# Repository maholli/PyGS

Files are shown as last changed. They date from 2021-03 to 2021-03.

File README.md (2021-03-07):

# PyGS
Simple wifi ground station running circuitpython 



## Example Hardware Setup
As opposed to using an antenna+rotator for receiving satellites moving across the sky, another option is to use multiple antennas like this:


attached to multiple low-cost radios.

# Detailed Instructions
To replicate the above example, you'll need the following:

## Items Required
- [ ] 1ea [FeatherS2](https://www.adafruit.com/product/4769)
- [ ] 3ea RFM9x Featherwing [900 MHz](https://www.adafruit.com/product/3231) or [433MHz](https://www.adafruit.com/product/3232)
- [ ] 3ea edge-mount [SMA connectors ](https://www.adafruit.com/product/1865)
- [ ] 4ea [Stacking headers](https://www.adafruit.com/product/2830)
- [ ] Directional antennas for each of your radios. [Log Periodic](https://www.wa5vjb.com/products1.html) antennas work well. The LP400 covers 433MHz and 915MHz.
- [ ] Coax cables for each radio+antenna. Each cable should be about 450mm.
- [ ] Battery for the FeatherS2. [This would work well ](https://www.adafruit.com/product/353)
- [ ] Husky storage bin (overkill but convenient) [from Home Depot](https://www.homedepot.com/p/Husky-20-Gal-Professional-Duty-Waterproof-Storage-Container-with-Hinged-Lid-in-Black-246841/312898941)
- [ ] OPTIONAL: 2ea 100kΩ resistors (0603 work well) for battery voltage monitor

## Hardware Setup
### Antennas
1. 3D print the antenna spacer: 
2. Connect your coax and tape at the base. Ensure the coax runs on top of the center trace of the LP antenna.

### Radios & MCU
The hardware from Adafruit needs to be assembled as described below. Keep in mind you can always adapt the pin definitions in `radio_helpers.py` to meet a different hardware configuration. 
1. Assemble the radio boards with stacking headers and your edge-mount SMA connectors. Use [Adafruit's guide](https://learn.adafruit.com/radio-featherwing/assembly) as a reference.
2. Solder wires for the radio CS, RST, and IRQ signals as described below:


| Radio | CS | RST | IRQ |
|:-----: |:---:  |:---:  |:---:  |
| 1 | "C" | "B" | See pic |
| 2 | "E" | "D" | See pic |
| 3 | See pic | See pic | See pic | 

3. Now assemble the FeatherS2 with stacking headers
4. In order to monitor battery voltage, we need to add a voltage divider. Solder your two 100kΩ resistors as shown below.



### Software
1. Update the FeatherS2 firmware using the .UF2 file in this repo's firmware directory. This can be done by putting the board into bootloader mode (plug into computer, click reset button, then click boot button) and then dragging the UF2 file onto the `FeatherS2` drive that should mount shortly. It will likely have an error while copying the file. Don't worry about it.
2. Unplug and plug the board back into your computer
3. Copy the contents of the `code` directory from this repo to the CIRCUITPY drive
4. On the CIRCUITPY drive, open the `RENAME_ME.py` file in the lib folder and update the mqtt broker info and save
5. Now rename the `RENAME_ME.py` file to: `secrets.py`
6. Open `code.py` and edit line 32 to your respective WiFi SSID

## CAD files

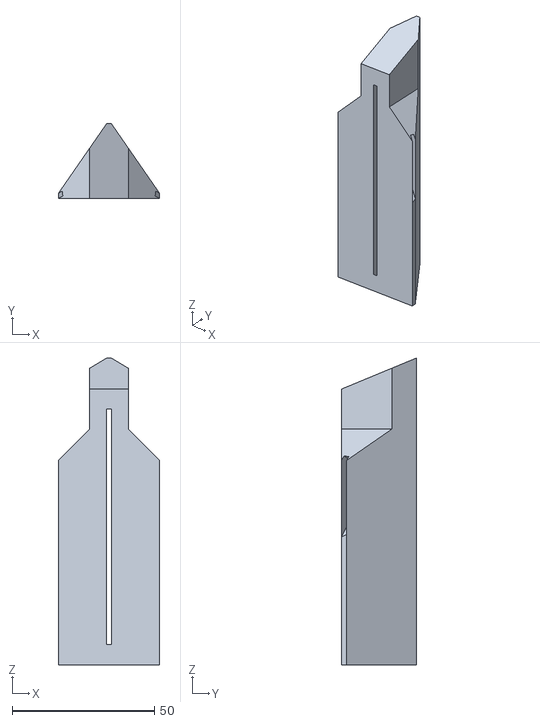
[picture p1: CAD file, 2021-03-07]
antenna_spacer.stl
35.6 x 26.4 x 108.0

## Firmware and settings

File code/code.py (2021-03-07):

import wifi, socketpool, time, alarm
import adafruit_minimqtt.adafruit_minimqtt as MQTT
from radio_helpers import gs, mqtt_message, connected
from secrets import secrets
import storage,os,board, json
from binascii import hexlify

gs.ID = 'A'
DATA_TOPIC = 'gs/testsub'
CTRL_TOPIC = 'gs/remote'+gs.ID
SAT = gs.SATELLITE['VR3X']

radios=[]
# if we haven't slept yet, init radios
if not alarm.wake_alarm:
    print('First boot')
    radios = gs.init_radios(SAT)
    # reset counters
    gs.counter = 0
    gs.msg_count = 0
    gs.msg_cache = 0
    gs.deep_sleep = 600
else:
    radios={1:gs.R1_CS,2:gs.R2_CS,3:gs.R3_CS}


print('Loop: {}, Total Msgs: {}, Msgs in Cache: {}, Vbatt: {:.1f}'.format(gs.counter,gs.msg_count,gs.msg_cache,gs.battery_voltage))

# try connecting to wifi
print('Connecting to WiFi...')
try:
    wifi.radio.connect(ssid='RENAME ME') # open network

    print('Signal: {}'.format(wifi.radio.ap_info.rssi))
    # Create a socket pool
    pool = socketpool.SocketPool(wifi.radio)
    # sync out RTC from the web
    gs.synctime(pool)
except Exception as e:
    print('Unable to connect to WiFi: {}'.format(e))

# check radios
new_messages={}
if alarm.wake_alarm:
    # hacky way of checking the radios without initalizing the hardware
    for r in radios:
        if gs.rx_done(radios[r]):
            print(r,end=': ')
            for msg in gs.get_msg2(radios[r]):
                if msg is not None:
                    print('[{}] rssi:{}'.format(bytes(msg),gs.last_rssi), end=', ')
                    if msg is b'CRC ERROR':
                        continue
                    else:
                        # radio, time, gs id, msg, rssi, new?
                        new_messages[r]={"RD":r,"T":time.time(),"I":gs.ID,"MSG":hexlify(msg),"RS":gs.last_rssi,"N":1}
            print()
    radios = gs.init_radios(SAT)

if new_messages:
    gs.msg_count = gs.msg_count + 1

# if we have wifi, connect to mqtt broker
if wifi.radio.ap_info is not None:
    # try:
    # Set up a MiniMQTT Client
    mqtt_client = MQTT.MQTT(
        broker=secrets['broker'],
        port=secrets['port'],
        socket_pool=pool,
        is_ssl=False,
    )
    mqtt_client.on_connect = connected
    mqtt_client.on_message = mqtt_message

    status = {
        'T':time.time(),
        'I':gs.ID,
        '#':gs.counter,
        'M':gs.msg_count,
        'C':gs.msg_cache,
        'B':gs.battery_voltage,
        'R':wifi.radio.ap_info.rssi,
    }

    mqtt_client.connect()
    mqtt_client.subscribe(CTRL_TOPIC)
    mqtt_client.publish(DATA_TOPIC,json.dumps(status))

    # send any cached messages
    if gs.msg_cache:
        with open('/data.txt','r') as f:
            l=f.readline()
            while l:
                mqtt_client.publish(DATA_TOPIC,l.strip())
                l=f.readline()
        try: os.remove('/data.txt')
        except: pass
        gs.msg_cache=0

    # send any new messages
    if new_messages:
        for msg in new_messages:
            mqtt_client.publish(DATA_TOPIC,json.dumps(new_messages[msg]))
    # check for mqtt remote messages
    mqtt_client.loop()
    # break mqtt connection
    mqtt_client.disconnect()

# if we can't connect, cache message
else:
    for msg in new_messages:
        new_messages[msg]["N"]=0 # not new
        try:
            storage.remount('/',False)
            with open('/data.txt','a') as f:
                f.write(json.dumps(new_messages[msg])+'\n')
            storage.remount('/',True)
        except:
            print('Cant cache msg. Connected to usb?')
        gs.msg_cache=gs.msg_cache+1

gs.counter = gs.counter + 1

print('Finished. Deep sleep until RX interrupt or {}s timeout...'.format(gs.deep_sleep))
# wake up on IRQ or after deep sleep time
pin_alarm1 = alarm.pin.PinAlarm(pin=board.IO5, value=True, pull=False) # radio1
pin_alarm2 = alarm.pin.PinAlarm(pin=board.IO6, value=True, pull=False) # radio2
pin_alarm3 = alarm.pin.PinAlarm(pin=board.IO7, value=True, pull=False) # radio3
time_alarm = alarm.time.TimeAlarm(monotonic_time=time.monotonic() + gs.deep_sleep)
alarm.exit_and_deep_sleep_until_alarms(time_alarm,pin_alarm1,pin_alarm2,pin_alarm3)

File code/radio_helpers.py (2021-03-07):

import digitalio,board, time, alarm
import pycubed_rfm9x
import adafruit_requests,rtc,json
from microcontroller import cpu
from analogio import AnalogIn

FIFO = bytearray(256)
fifo_view = memoryview(FIFO)


def mqtt_message(client, feed_id, payload):
    print("[{0}] {1}".format(feed_id, payload))
    try:
        if payload[:2]=='EV':
            client.publish('gs/remote/response',str(eval(payload[2:])))
        elif payload[:2]=='EX':
            exec(payload[2:].encode())
        elif payload[:4]=='PING':
            client.publish('gs/remote/response',str(time.time()))
    except Exception as e:
        print('error: {}'.format(e))
        client.publish('gs/remote/response',str(e))

def connected(client, userdata, flags, rc):
    # This function will be called when the client is connected
    # successfully to the broker.
    print("Connected to MQTT broker!")

class GroundStation:
    myuid=int.from_bytes(cpu.uid,'big')
    last_rssi=0

    SATELLITE = {
        'NORBI':{'NAME':'NORBI','FREQ':436.703,'SF':10,'BW':250000,'CR':8},
        'VR3X' :{'NAME':'VR3X','FREQ':915.6,'SF':7,'BW':62500,'CR':8}
    }

    def __init__(self):
        self.vbatt = AnalogIn(board.IO17)
        LED= digitalio.DigitalInOut(board.LED)
        LED.switch_to_output(True)
        self.spi=board.SPI()
        self.R1_CS  = digitalio.DigitalInOut(board.D5)
        self.R2_CS  = digitalio.DigitalInOut(board.D20)
        self.R3_CS  = digitalio.DigitalInOut(board.D12)
        self.R1_CS.switch_to_output(True)
        self.R2_CS.switch_to_output(True)
        self.R3_CS.switch_to_output(True)
        self._BUFFER=bytearray(256)

    @property
    def battery_voltage(self):
        _v=0
        for _ in range(20):
            _v+=self.vbatt.value
        _v=2*((_v/20)*3.3/65536)
        return _v


    def init_radios(self,config):
        # define radio pins
        # 1 - RST:B(D61/D6) CS:C(DAC0/D5)  IRQ:IO5
        R1_RST = digitalio.DigitalInOut(board.D6)
        R1_RST.switch_to_output(True)
        # 2 - RST:D(A7/D21) CS:E(A8/D20)   IRQ:IO6
        R2_RST = digitalio.DigitalInOut(board.D21)
        R2_RST.switch_to_output(True)
        # 3 - RST:D59/D12   CS:DAC1/D13    IRQ:IO7
        R3_RST = digitalio.DigitalInOut(board.D13)
        R3_RST.switch_to_output(True)

        # initialize radios
        radio1 = pycubed_rfm9x.RFM9x(board.SPI(),self.R1_CS,R1_RST,config['FREQ'],code_rate=config['CR'],baudrate=1320000)
        radio2 = pycubed_rfm9x.RFM9x(board.SPI(),self.R2_CS,R2_RST,config['FREQ'],code_rate=config['CR'],baudrate=1320000)
        radio3 = pycubed_rfm9x.RFM9x(board.SPI(),self.R3_CS,R3_RST,config['FREQ'],code_rate=config['CR'],baudrate=1320000)
        radio1.name=1
        radio2.name=2
        radio3.name=3
        # configure radios
        for r in (radio1,radio2,radio3):
            r.node = 0x33 # ground station ID
            r.idle()
            r.spreading_factor=config['SF']
            r.signal_bandwidth=config['BW']
            r.coding_rate=config['CR']
            r.preamble_length = 8
            r.enable_crc=True
            r.low_datarate_optimize = True
            r.ack_wait=2
            r.ack_delay=0.2
            r.ack_retries=0
            r.listen()
        return (radio1,radio2,radio3)


    def synctime(self,pool):
        try:
            requests = adafruit_requests.Session(pool)
            TIME_API = "http://worldtimeapi.org/api/ip"
            the_rtc = rtc.RTC()
            response = None
            while True:
                try:
                    print("Fetching time")
                    # print("Fetching json from", TIME_API)
                    response = requests.get(TIME_API)
                    break
                except (ValueError, RuntimeError) as e:
                    print("Failed to get data, retrying\n", e)
                    continue

            json1 = response.json()
            # print(json1)
            current_time = json1['datetime']
            the_date, the_time = current_time.split('T')
            year, month, mday = [int(x) for x in the_date.split('-')]
            the_time = the_time.split('.')[0]
            hours, minutes, seconds = [int(x) for x in the_time.split(':')]

            # We can also fill in these extra nice things
            year_day = json1['day_of_year']
            week_day = json1['day_of_week']
            is_dst = json1['dst']

            now = time.struct_time((year, month, mday, hours, minutes, seconds, week_day, year_day, is_dst))
            the_rtc.datetime = now
        except Exception as e:
            print('[WARNING]',e)

    @property
    def counter(self):
        return int.from_bytes(alarm.sleep_memory[0:2],'big')
    @counter.setter
    def counter(self,value):
        alarm.sleep_memory[0:2] = int(value % 65536).to_bytes(2,'big')

    @property
    def msg_count(self):
        return int.from_bytes(alarm.sleep_memory[2:4],'big')
    @msg_count.setter
    def msg_count(self,value):
        alarm.sleep_memory[2:4] = int(value % 65536).to_bytes(2,'big')

    @property
    def msg_cache(self):
        return alarm.sleep_memory[4]
    @msg_cache.setter
    def msg_cache(self,value):
        alarm.sleep_memory[4] = value

    @property
    def deep_sleep(self):
        return int.from_bytes(alarm.sleep_memory[5:7],'big')
    @deep_sleep.setter
    def deep_sleep(self,value):
        alarm.sleep_memory[5:7] = int(value % 65536).to_bytes(2,'big')

    def _read_into(self, radio_cs, address, buf, length=None):
        if length is None:
            length = len(buf)
        self._BUFFER[0] = address & 0x7F  # Strip out top bit to set read value
        radio_cs.value=False
        self.spi.try_lock()
        self.spi.write(bytes([(address & 0x7F)]))
        self.spi.readinto(buf,end=length)
        radio_cs.value=True
        self.spi.unlock()
        # print(buf)

    def _read_u8(self,radio_cs,address):
        self._read_into(radio_cs,address,self._BUFFER,1)
        return self._BUFFER[0]

    def _write_u8(self, radio_cs, address, val):
        radio_cs.value=False
        self.spi.try_lock()
        self._BUFFER[0] = (address | 0x80) & 0xFF  # Set top bit to 1
        self._BUFFER[1] = val & 0xFF
        self.spi.write(self._BUFFER, end=2)
        radio_cs.value=True
        self.spi.unlock()

    def rx_done(self,radio_cs):
        return (self._read_u8(radio_cs,0x12) & 0x40) >> 6
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

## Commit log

2021-02-17 working radio+mqtt example publishing via public IP to self hosted broker
    [radio_helpers.py]
2021-03-07 adding antenna spacer STL
    [antenna_spacer.stl]
